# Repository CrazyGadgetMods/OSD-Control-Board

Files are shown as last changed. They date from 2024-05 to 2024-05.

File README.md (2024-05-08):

# OSD Control Board
This OSD board is a simple set of logic gates that allow the screen driver boards used in portables to be controlled with button combinations from the built-in controller. This was a first-rev board *very* early venture into PCB design, so it could definitely use some tweaks like decoupling caps for the logic gates, and the use of a proper ground plane. The board works fine as-is, or you could integrate it into your own design!

## Using the Board
LT, RT, Z and S held together trigger the master key which, in combination with the following buttons will trigger the outputs wired to the screen driver board:
- DU: +
- DD: -
- DL: Source
- DR: Menu

Keep in mind, you can change the master button combination (or any of the other buttons) to better fit to your portable. For example, I like to wire S on the OSD board to Z2 on my GC+ in all my Ashidas, as the original button combination was not ergonomic. Likewise, you can tie multiple inputs together if you want a master combo with less buttons.

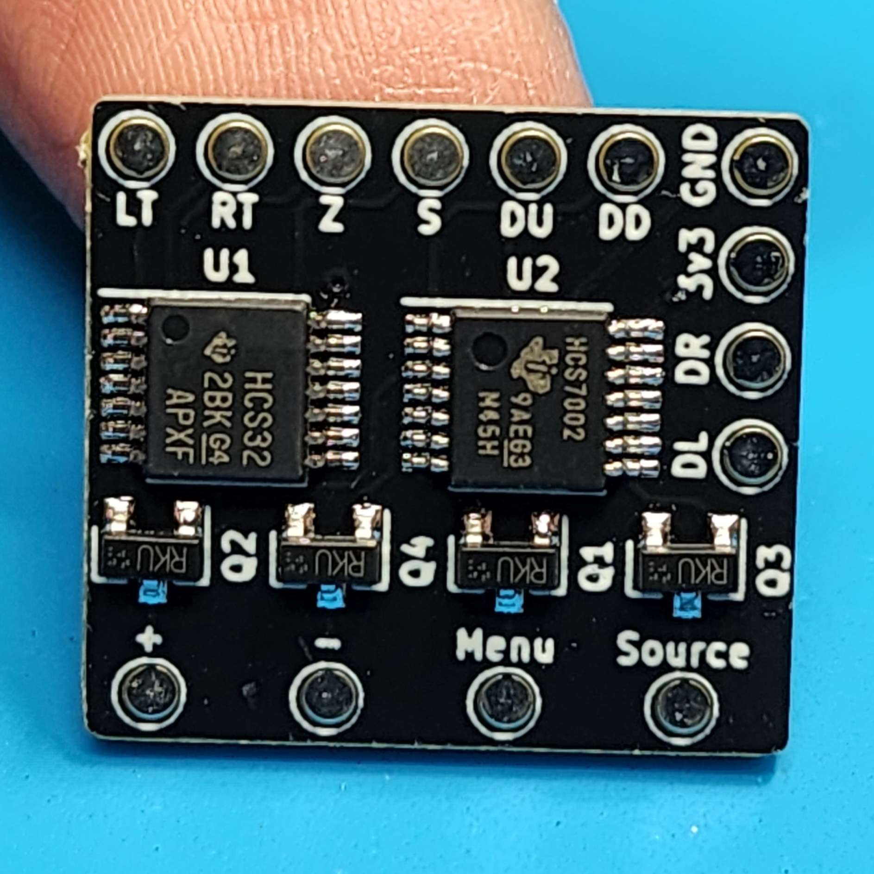
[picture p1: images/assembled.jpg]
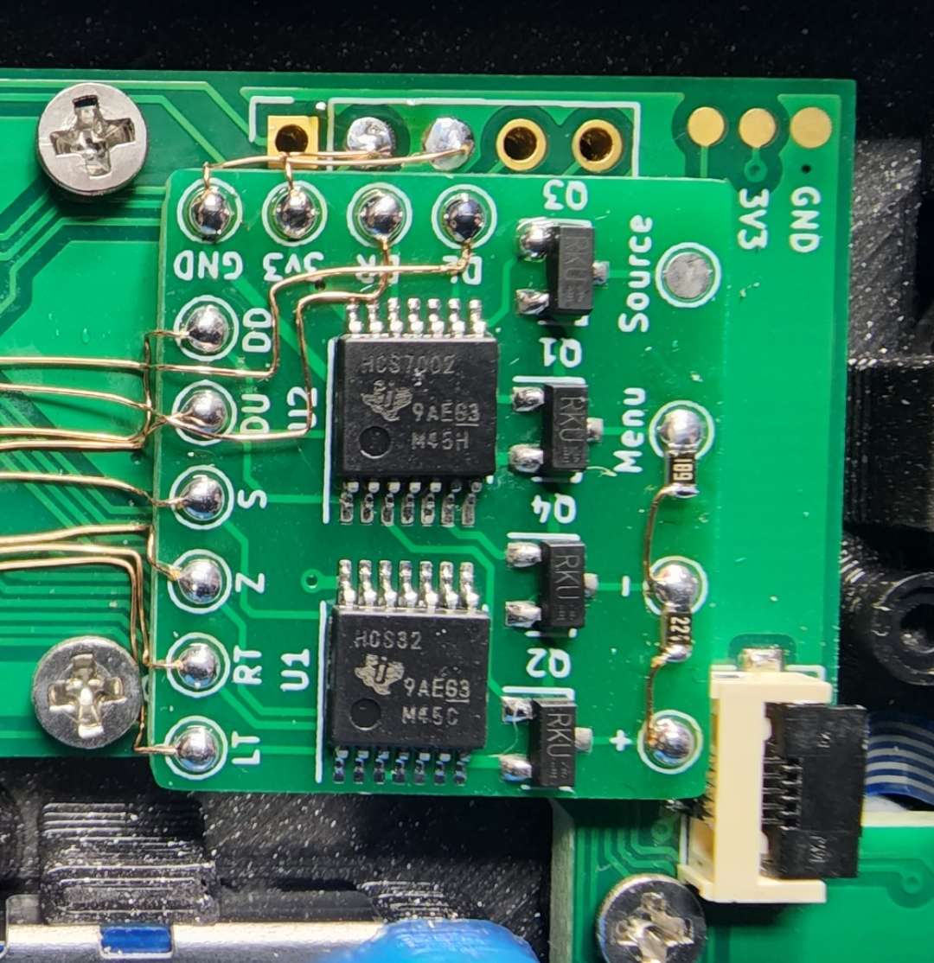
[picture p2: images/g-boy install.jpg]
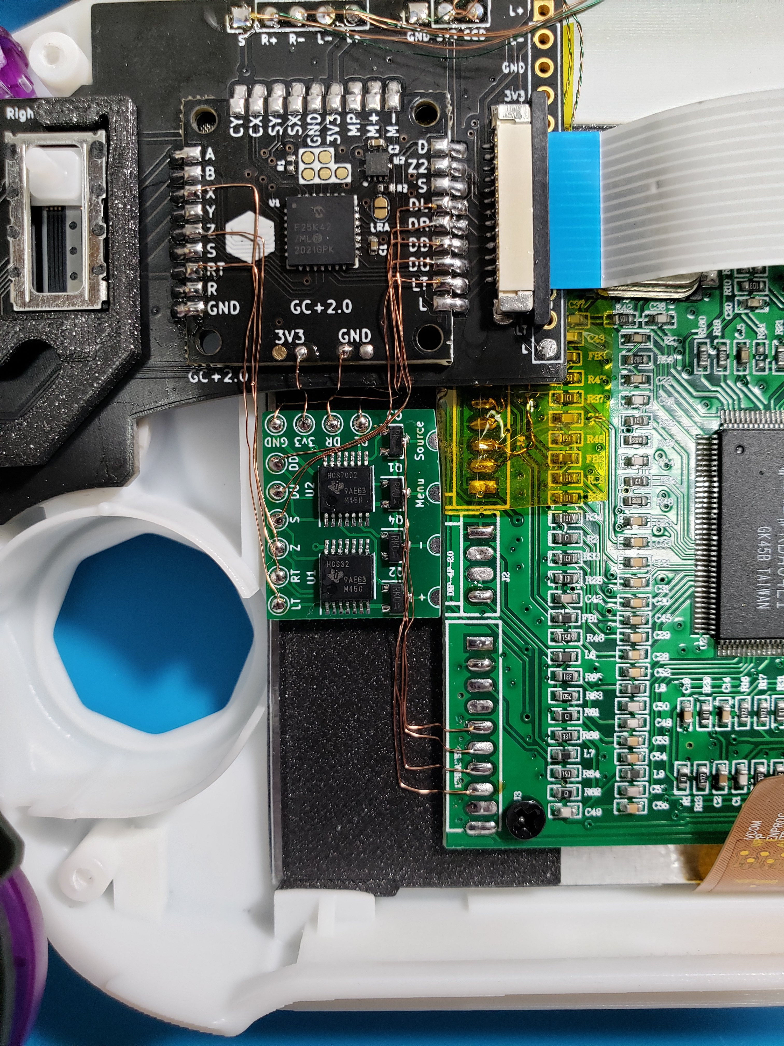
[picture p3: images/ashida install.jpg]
  

## Credits
- [BitBuilt](https://bitbuilt.net/): Being the best modding community out there!
- [Gman](https://github.com/Gmanmodz): Sanity checking

## License
Solderpad Hardware License v2.1

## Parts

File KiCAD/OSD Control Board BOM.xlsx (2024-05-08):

Ref Des | Qty | Manufacturer PN | Digikey PN | Description
U1 | 1 | SN74HCS32PWR | 296-SN74HCS32PWRCT-ND | IC GATE OR 4CH 2IN 14TSSOP
U2 | 1 | SN74HCS7002PWR | 296-SN74HCS7002PWRCT-ND | IC GATE NOR 4CH 2-INP 14TSSOP
Q1, Q2, Q3, Q4 | 4 | RK7002BMT116 | RK7002BMT116CT-ND | MOSFET N-CH 60V 250MA SST3

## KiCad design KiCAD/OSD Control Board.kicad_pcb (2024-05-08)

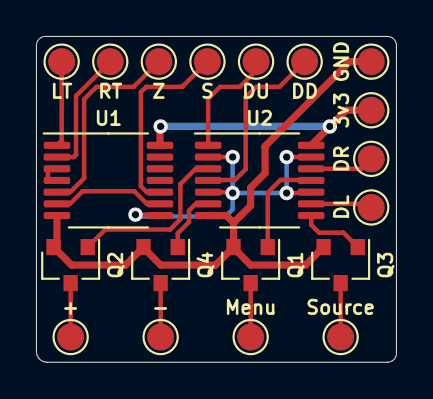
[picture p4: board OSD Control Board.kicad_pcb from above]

Board: 2 copper layers, 20.0 x 18.1 mm, 20 parts (0 on the bottom side), 21 nets.

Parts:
3v3: 3v3; TestPoint_Pad_D1.5mm
+: +; TestPoint_Pad_D1.5mm
-: -; TestPoint_Pad_D1.5mm
DD: DD; TestPoint_Pad_D1.5mm
DL: DL; TestPoint_Pad_D1.5mm
DR: DR; TestPoint_Pad_D1.5mm
DU: DU; TestPoint_Pad_D1.5mm
GND: GND; TestPoint_Pad_D1.5mm
LT: LT; TestPoint_Pad_D1.5mm
Menu: Menu; TestPoint_Pad_D1.5mm
Q1, Q2, Q3, Q4: NX138AKR; SOT-23
RT: RT; TestPoint_Pad_D1.5mm
S: S; TestPoint_Pad_D1.5mm
Source: Source; TestPoint_Pad_D1.5mm
U1: SN74HCS32PWR; TSSOP-14_4.4x5mm_P0.65mm
U2: SN74HCS7002PWR; TSSOP-14_4.4x5mm_P0.65mm
Z: Z; TestPoint_Pad_D1.5mm

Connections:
+3V3: 3v3.1, U1.14, U2.14
/2A: U1.3, U1.4
/3A: U1.6, U1.9
/+N: Q2.1, U2.3
/-N: Q4.1, U2.6
/DD: DD.1, U2.4
/DL: DL.1, U2.9
/DR: DR.1, U2.12
/DU: DU.1, U2.1
/LT: LT.1, U1.1
/MenuN: Q1.1, U2.11
/OR_OUT: U1.8, U2.2, U2.5, U2.10, U2.13
/RT: RT.1, U1.2
/S: S.1, U1.10
/SourceN: Q3.1, U2.8
/Z: U1.5, Z.1
GND: GND.1, Q1.2, Q2.2, Q3.2, Q4.2, U1.7, U2.7
unnamed: Menu.1, Q1.3
unnamed: +.1, Q2.3
unnamed: Q3.3, Source.1
unnamed: -.1, Q4.3
